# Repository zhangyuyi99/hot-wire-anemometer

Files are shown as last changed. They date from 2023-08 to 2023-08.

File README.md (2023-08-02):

# Hot wire anemometer

This project includes the design and implementation of a Wi-Fi enabled anemometer. The anemometer consists of a hardware portion which includes the PCB designs for the main board and logic board and a software portion which includes the firmware for operating the anemometer. The anemometer uses a hot wire method for wind speed measurement, and it includes a function to monitor battery voltage, disabling wind readings when the voltage drops below 7V until it recovers.

## Contents
1. [Hardware](#Hardware)
2. [Software](#Software)
3. [Usage](#Usage)
4. [File Structure](#File-Structure)

## Hardware
The hardware part consists of two boards: 

### Main Board
The main board uses the analog hot wire anemometer method for wind measurement. It is powered and sends signal to the logic board.

### Logic Board
The logic board contains an ESP32 processor which receives signals from the main board. It sends the data either via a serial port or Wi-Fi. It also monitors the battery voltage and provides visual feedback using LEDs.

## Software
The software part consists of firmware written for the ESP32 processor. The firmware contains routines to read data from the main board, manage Wi-Fi connectivity, monitor battery voltage, and control LED indicators.

### Python Scripts
There are two Python scripts provided for reading data:

1. `read_from_esp32.py`: Reads data over Wi-Fi. To use this, the anemometer and the computer receiving data must be on the same Wi-Fi network.

2. `read_from_esp32_serial.py`: Reads data over a serial port.

## Usage

To use this anemometer, you will need to:

1. Print the main board and logic board based on the provided PCB design files.
2. Perform necessary wirings to power up the main board and send signals to the logic board.
3. Set up Wi-Fi connectivity in the firmware.
4. Compile and upload the firmware to the logic board.
5. Calibrate the anemometer. To calibrate, place the anemometer in an environment with the same ambient temperature as the actual measurement environment. Adjust the Through Hole Potentiometer on each anemometer until the no-wind reading reaches 1000-1200. Each anemometer is paired with a green LED on the logic board. The LED lights up when the no-wind reading is in the desired range.
6. Run the provided Python scripts to receive and save the wind data. Each wind data packet is a string of numbers separated by commas. The first number is a timestamp, and the rest are the anemometer readings.

## Modes

The anemometer supports four running modes:
* READ_ANEMOMETER
* SEND_PIN_READ
* PRINT_IP
* CALIBRATE

The default mode is CALIBRATE.

## File Structure

The files in this project are organized as follows:

- plot.pptx
- logic_board/
    - Various KiCAD and SVG files for logic board design
- main_board/
    - Various KiCAD and SVG files for main board design
- firmware/
    - anemometer/
        - Python scripts to read data from the anemometer
        - ESP32 firmware files
        - Additional files for Visual Studio Code and PlatformIO

For a detailed view of the file structure, refer to the file list provided earlier.

## Note

The readings of different anemometers for the same wind strength might not be the same. However, the change in readings should accurately reflect the changes in wind conditions.

## Contribution 

The design of main board and logic board is done by Filip Ayazi. The firmware is written by Yuyi Zhang and ChatGPT, actually mostly by ChatGPT.

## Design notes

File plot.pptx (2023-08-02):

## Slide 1

9

8

Connection2
ADC 1
GPIO 2

Connection9
ADC 0
GPIO 1

Connection5
ADC 9
GPIO 10

Connection
ADC 8
GPIO 9

Anemometer | GPIO
1 | 4
2 | 2
3 | 10
4 | 3
5 | 8
6 | 5
7 | 9
8 | 1
9 | 7

7

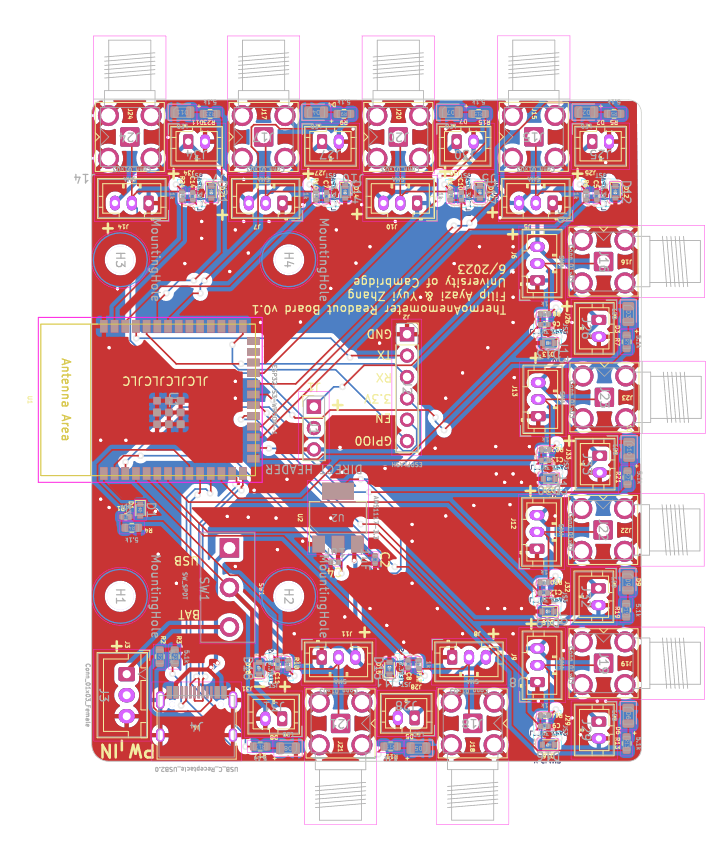
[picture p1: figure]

6

Connection 1
ADC 2
GPIO 3

5

Connection 8
ADC 7
GPIO 8

4

Connection 7
ADC 6
GPIO 7

3

2

Connection 6
ADC3
GPIO4

Connection 3
ADC4
GPIO5

1

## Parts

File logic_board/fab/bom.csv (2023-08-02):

Comment | Designator | Footprint | LCSC
DIRECT_HEADER | J1 | Connector_PinHeader_2.54mm:PinHeader_1x03_P2.54mm_Vertical | C5116482
USB_C_Receptacle_USB2.0 | J4 | Connector_USB:USB_C_Receptacle_HRO_TYPE-C-31-M-12 | C2765186
3.3V | D1,D12,D13,D14,D15,D16,D17,D18,D19,D20,D21 | Diode_SMD:D_SOD-523 | C2999960
1uF | C2,C4,C5,C6,C7,C8,C9,C10,C11,C12,C13,C14 | Capacitor_SMD:C_0402_1005Metric | C301999
10k | R1 | Resistor_SMD:R_0402_1005Metric | C407753
Conn_01x03_Female | J3 | Connector_JST:JST_XH_B3B-XH-A_1x03_P2.50mm_Vertical | C144394
5.1k | R2,R3,R4,R5,R7,R9,R11,R13,R15,R17,R19,R21,R23 | Resistor_SMD:R_0603_1608Metric | C25197
SW_SPDT | SW1 | library:switch_4.7mm | C319012
ESP32-S3-WROOM-1 | U1 | PCM_Espressif:ESP32-S3-WROOM-1 | C2913197
AMS1117-3.3 | U2 | Package_TO_SOT_SMD:SOT-223-3_TabPin2 | C173386
ESPFLASH | J2 | Connector_PinSocket_2.54mm:PinSocket_1x06_P2.54mm_Vertical | C5224026
JST | J25,J26,J27,J28,J29,J30,J31,J32,J33,J34 | Connector_JST:JST_PH_B2B-PH-K_1x02_P2.00mm_Vertical | C131337
SMA | J15,J16,J17,J18,J19,J20,J21,J22,J23,J24 | library:SMA_Amphenol_901-143_Horizontal | C411575
1k | R6,R8,R10,R12,R14,R16,R18,R20,R22,R24 | Resistor_SMD:R_0402_1005Metric | C208774
LED | D2,D3,D4,D5,D6,D7,D8,D9,D10,D11 | LED_SMD:LED_0805_2012Metric | C2297
Conn_01x03 | J5,J6,J7,J8,J9,J10,J11,J12,J13,J14 | Connector_JST:JST_PH_B3B-PH-K_1x03_P2.00mm_Vertical | C131339

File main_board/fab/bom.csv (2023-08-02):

Comment | Designator | Footprint | LCSC
HEADER | J3 | Connector_PinSocket_2.54mm:PinSocket_1x03_P2.54mm_Vertical | C358717
1nF | C5 | Capacitor_SMD:C_0402_1005Metric | C93920
PWR | J6 | Connector_JST:JST_PH_B2B-PH-K_1x02_P2.00mm_Vertical | C131337
470nF | C1,C4 | Capacitor_SMD:C_0402_1005Metric | C426055
AZ1117-5.0 | U3 | Package_TO_SOT_SMD:SOT-89-3 | C24248
wire+ | J1 | Library:m2.5_pad
wire- | J2 | Library:m2.5_pad
10k | R5 | Resistor_SMD:R_0603_1608Metric | C160601
47k | R3,R4 | Resistor_SMD:R_0603_1608Metric | C340515
JST3 | J7 | Connector_JST:JST_PH_B3B-PH-K_1x03_P2.00mm_Vertical | C131339
1K | R2 | Resistor_SMD:R_0603_1608Metric | C103198
SMA | J5 | Connector_Coaxial:SMA_Amphenol_901-143_Horizontal | C411575
5.1 | R1 | Resistor_SMD:R_2512_6332Metric | C105134
1uF | C2,C3 | Capacitor_SMD:C_0603_1608Metric | C106848
12k | R6 | Resistor_SMD:R_0603_1608Metric | C2984432
LM317_TO-220 | U2 | Package_TO_SOT_SMD:SOT-223 | C347367
10k | RV1 | Potentiometer_THT:Potentiometer_Bourns_3386P_Vertical | C118953
LM358 | U1 | Package_SO:SOP-8_3.76x4.96mm_P1.27mm | C5252902

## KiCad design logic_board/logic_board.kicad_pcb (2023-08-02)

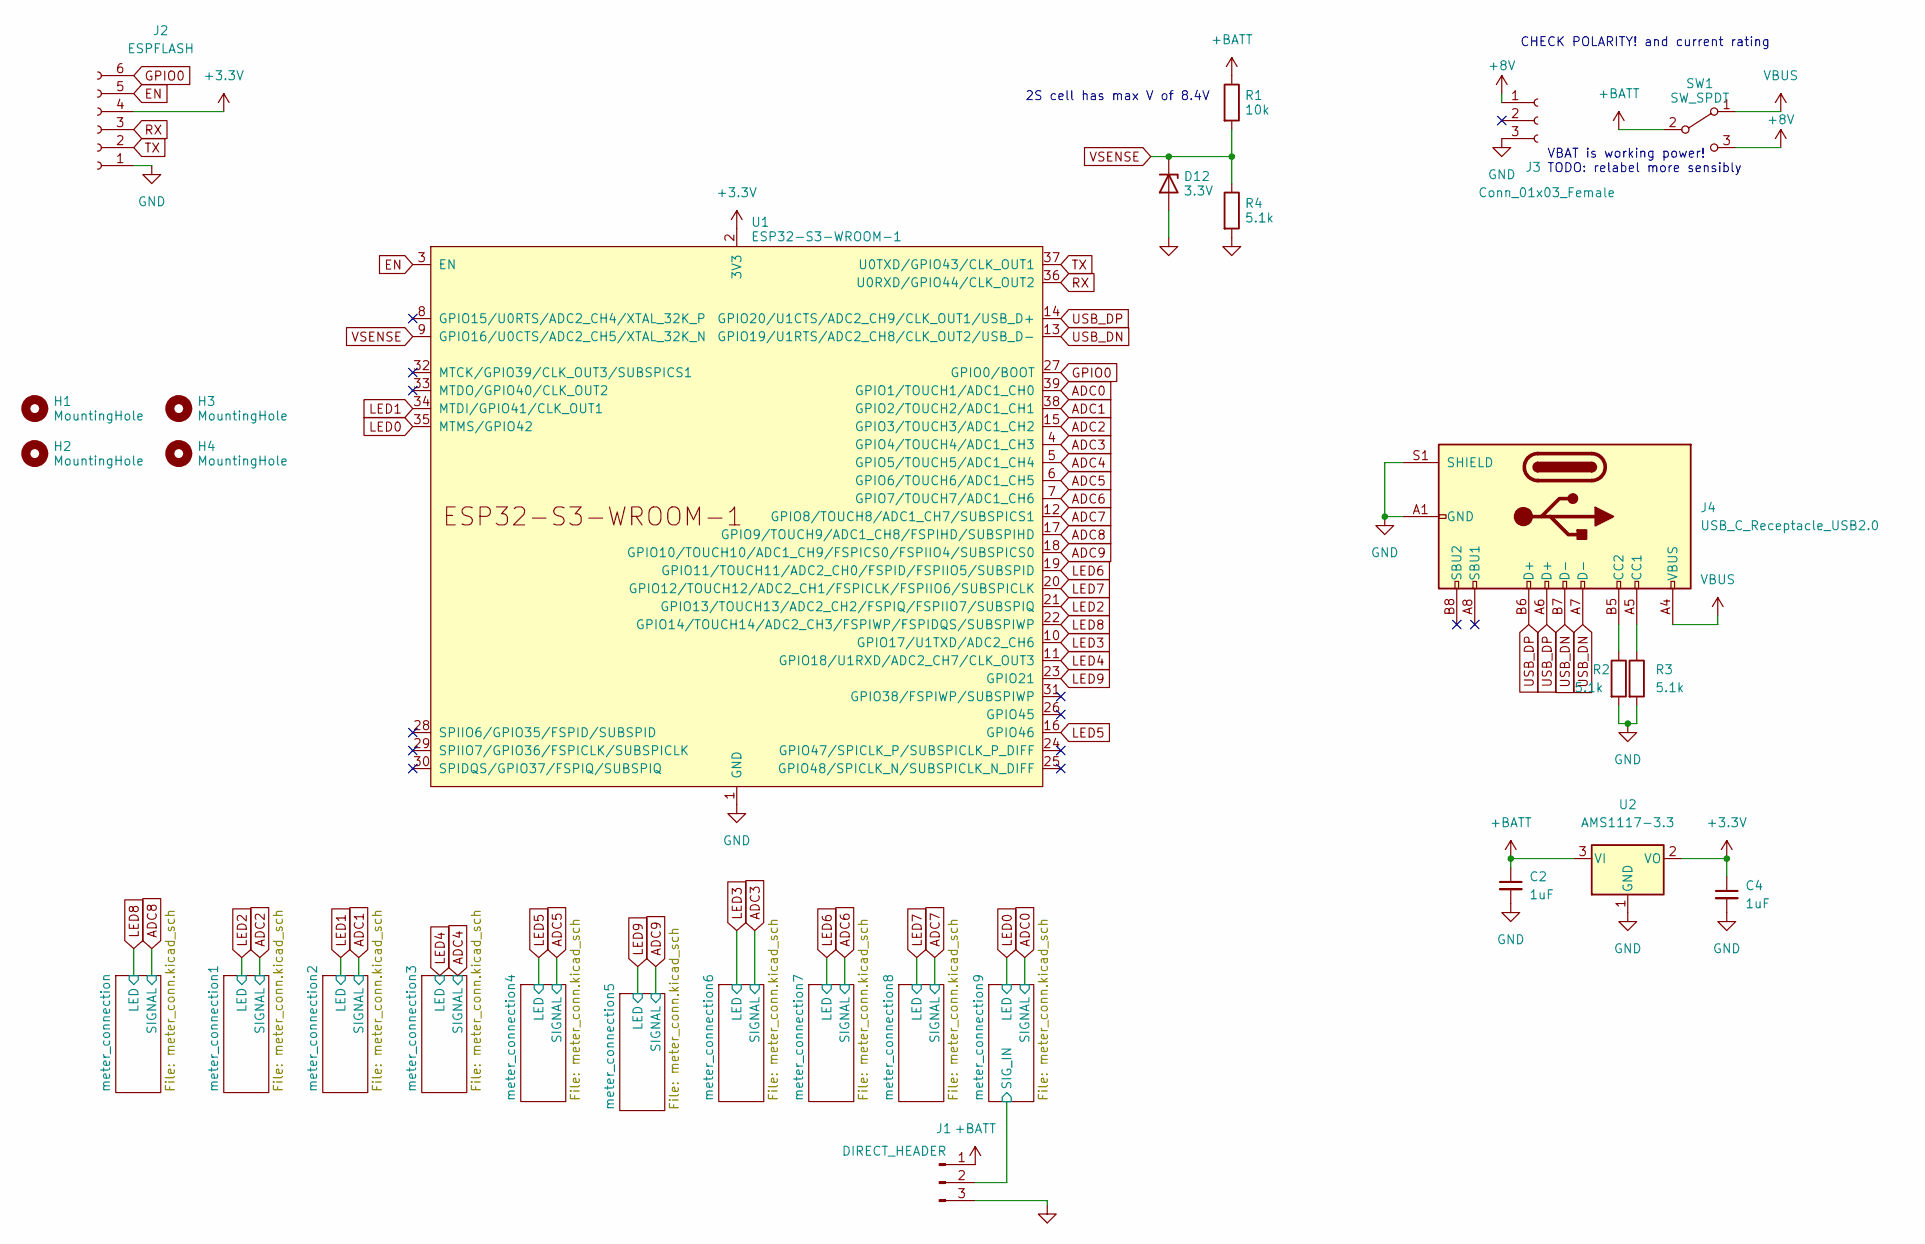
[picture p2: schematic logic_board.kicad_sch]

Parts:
C2, C4: 1uF; C_0402_1005Metric; JLC C83063
D12: 3.3V; D_SOD-523; JLC C2999960
H1, H2, H3, H4: MountingHole; MountingHole_3.2mm_M3
J1: DIRECT_HEADER; PinHeader_1x03_P2.54mm_Vertical; JLC C5116482
J2: ESPFLASH; PinSocket_1x06_P2.54mm_Vertical; JLC C5224026
J3: Conn_01x03_Female; JST_XH_B3B-XH-A_1x03_P2.50mm_Vertical; JLC C144394
J4: USB_C_Receptacle_USB2.0; USB_C_Receptacle_HRO_TYPE-C-31-M-12; JLC C2765186
R1: 10k; R_0402_1005Metric; JLC C407753
R2, R3, R4: 5.1k; R_0603_1608Metric; JLC C105580
SW1: SW_SPDT; switch_4.7mm; JLC C319012
U1: ESP32-S3-WROOM-1; JLC C2913197
U2: AMS1117-3.3; SOT-223-3_TabPin2; JLC C173386

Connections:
+3V3: C4.1, J2.4, U1.2 (3V3), U2.2 (VO)
+8V: J3.1, SW1.3 (C)
+BATT: C2.1, J1.1, R1.1, SW1.2 (B), U2.3 (VI); also elsewhere on the board
/meter_connection9/SIG_IN: J1.2; also elsewhere on the board
ADC0: U1.39 (GPIO1/TOUCH1/ADC1_CH0); also elsewhere on the board
ADC1: U1.38 (GPIO2/TOUCH2/ADC1_CH1); also elsewhere on the board
ADC2: U1.15 (GPIO3/TOUCH3/ADC1_CH2); also elsewhere on the board
ADC3: U1.4 (GPIO4/TOUCH4/ADC1_CH3); also elsewhere on the board
ADC4: U1.5 (GPIO5/TOUCH5/ADC1_CH4); also elsewhere on the board
ADC5: U1.6 (GPIO6/TOUCH6/ADC1_CH5); also elsewhere on the board
ADC6: U1.7 (GPIO7/TOUCH7/ADC1_CH6); also elsewhere on the board
ADC7: U1.12 (GPIO8/TOUCH8/ADC1_CH7/SUBSPICS1); also elsewhere on the board
ADC8: U1.17 (GPIO9/TOUCH9/ADC1_CH8/FSPIHD/SUBSPIHD); also elsewhere on the board
ADC9: U1.18 (GPIO10/TOUCH10/ADC1_CH9/FSPICS0/FSPIIO4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); also elsewhere on the board
EN: J2.5, U1.3 (EN)
GND: C2.2, C4.2, D12.2 (A), J1.3, J2.1, J3.3, J4.A1 (GND), J4.A12 (GND), J4.B1 (GND), J4.B12 (GND), J4.S1 (SHIELD), R2.2, R3.2, R4.2, U1.1 (GND), U1.40 (GND), U1.41 (GND), U2.1 (GND); also elsewhere on the board
GPIO0: J2.6, U1.27 (GPIO0/BOOT)
LED0: U1.35 (MTMS/GPIO42); also elsewhere on the board
LED1: U1.34 (MTDI/GPIO41/CLK_OUT1); also elsewhere on the board
LED2: U1.21 (GPIO13/TOUCH13/ADC2_CH2/FSPIQ/FSPIIO7/S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); also elsewhere on the board
LED3: U1.10 (GPIO17/U1TXD/ADC2_CH6); also elsewhere on the board
LED4: U1.11 (GPIO18/U1RXD/ADC2_CH7/CLK_OUT3); also elsewhere on the board
LED5: U1.16 (GPIO46); also elsewhere on the board
LED6: U1.19 (GPIO11/TOUCH11/ADC2_CH0/FSPID/FSPIIO5/S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); also elsewhere on the board
LED7: U1.20 (GPIO12/TOUCH12/ADC2_CH1/FSPICLK/FSPIIO6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); also elsewhere on the board
LED8: U1.22 (GPIO14/TOUCH14/ADC2_CH3/FSPIWP/FSPIDQS/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); also elsewhere on the board
LED9: U1.23 (GPIO21); also elsewhere on the board
unnamed: J4.A5 (CC1), R3.1
unnamed: J4.B5 (CC2), R2.1
RX: J2.3, U1.36 (U0RXD/GPIO44/CLK_OUT2)
TX: J2.2, U1.37 (U0TXD/GPIO43/CLK_OUT1)
USB_DN: J4.A7 (D-), J4.B7 (D-), U1.13 (GPIO19/U1RTS/ADC2_CH8/CLK_OUT2/USB_D-)
USB_DP: J4.A6 (D+), J4.B6 (D+), U1.14 (GPIO20/U1CTS/ADC2_CH9/CLK_OUT1/USB_D+)
VBUS: J4.A4 (VBUS), J4.A9 (VBUS), J4.B4 (VBUS), J4.B9 (VBUS), SW1.1 (A)

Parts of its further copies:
D1, D13, D14, D15, D16, D17, D18, D19, D20, D21: 3.3V; D_SOD-523; JLC C2999960

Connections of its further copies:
GND: D1.2 (A), D13.2 (A), D14.2 (A), D15.2 (A), D16.2 (A), D17.2 (A), D18.2 (A), D19.2 (A), D20.2 (A), D21.2 (A); also elsewhere on the board
unnamed 46: D13.1 (K); also elsewhere on the board
unnamed 47: D14.1 (K); also elsewhere on the board
unnamed 48: D15.1 (K); also elsewhere on the board
unnamed 49: D16.1 (K); also elsewhere on the board
unnamed 50: D17.1 (K); also elsewhere on the board
unnamed 51: D18.1 (K); also elsewhere on the board
unnamed 52: D19.1 (K); also elsewhere on the board
unnamed 53: D20.1 (K); also elsewhere on the board
unnamed 54: D21.1 (K); also elsewhere on the board

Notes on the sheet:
2S cell has max V of 8.4V
VBAT is working power! TODO: relabel more sensibly
CHECK POLARITY! and current rating

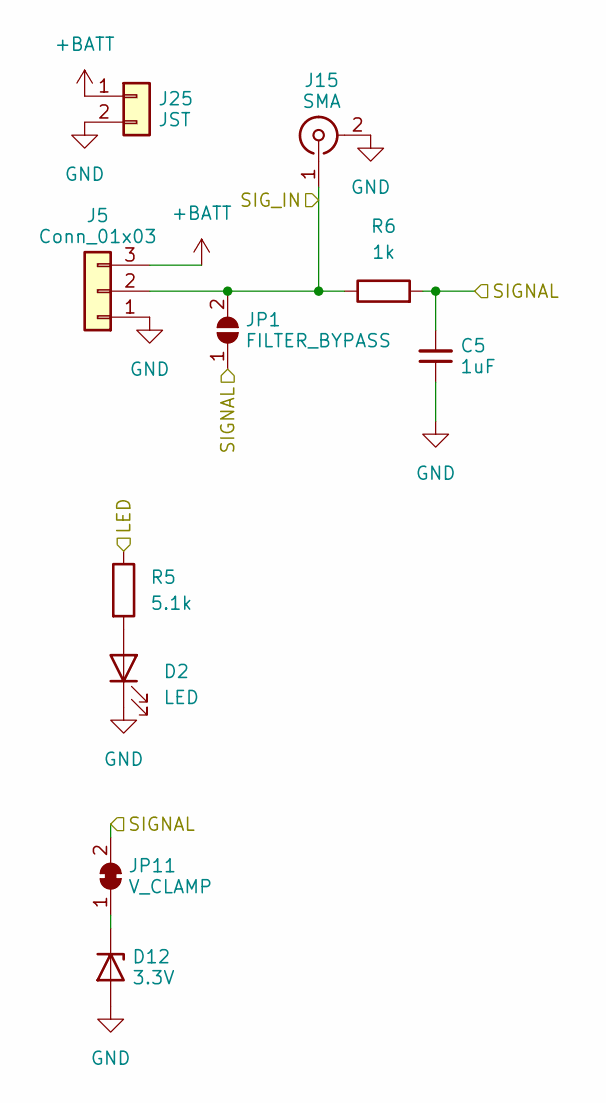
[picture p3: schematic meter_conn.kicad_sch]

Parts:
C5: 1uF; C_0402_1005Metric; JLC C83063
D2: LED; LED_0805_2012Metric; JLC C2297
D12: 3.3V; D_SOD-523; JLC C2999960
J5: Conn_01x03; JST_PH_B3B-PH-K_1x03_P2.00mm_Vertical; JLC C131339
J15: SMA; SMA_Amphenol_901-143_Horizontal; JLC C411575
J25: JST; JST_PH_B2B-PH-K_1x02_P2.00mm_Vertical; JLC C131337
JP1: FILTER_BYPASS; SolderJumper-2_P1.3mm_Open_RoundedPad1.0x1.5mm
JP11: V_CLAMP; SolderJumper-2_P1.3mm_Bridged2Bar_RoundedPad1.0x1.5mm
R5: 5.1k; R_0603_1608Metric; JLC C105580
R6: 1k; R_0402_1005Metric; JLC C208774

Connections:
+BATT: J5.3, J25.1; also elsewhere on the board
/meter_connection/SIG_IN: J5.2, J15.1 (In), JP1.2 (B), R6.1
ADC8: C5.2, JP1.1 (A), JP11.2 (B), R6.2; also elsewhere on the board
GND: C5.1, D2.1 (K), D12.2 (A), J5.1, J15.2 (Ext), J25.2; also elsewhere on the board
LED8: R5.1; also elsewhere on the board
unnamed: D2.2 (A), R5.2

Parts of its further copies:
C6, C7, C8, C9, C10, C11, C12, C13, C14: 1uF; C_0402_1005Metric; JLC C83063
D3, D4, D5, D6, D7, D8, D9, D10, D11: LED; LED_0805_2012Metric; JLC C2297
D13, D14, D15, D16, D17, D18, D19, D20, D21: 3.3V; D_SOD-523; JLC C2999960
J6, J7, J8, J9, J10, J11, J12, J13, J14: Conn_01x03; JST_PH_B3B-PH-K_1x03_P2.00mm_Vertical; JLC C131339
J16, J17, J18, J19, J20, J21, J22, J23, J24: SMA; SMA_Amphenol_901-143_Horizontal; JLC C411575
J26, J27, J28, J29, J30, J31, J32, J33, J34: JST; JST_PH_B2B-PH-K_1x02_P2.00mm_Vertical; JLC C131337
JP2, JP3, JP4, JP5, JP6, JP7, JP8, JP9, JP10: FILTER_BYPASS; SolderJumper-2_P1.3mm_Open_RoundedPad1.0x1.5mm
JP12, JP13, JP14, JP15, JP16, JP17, JP18, JP19, JP20: V_CLAMP; SolderJumper-2_P1.3mm_Bridged2Bar_RoundedPad1.0x1.5mm
R7, R9, R11, R13, R15, R17, R19, R21, R23: 5.1k; R_0603_1608Metric; JLC C105580
R8, R10, R12, R14, R16, R18, R20, R22, R24: 1k; R_0402_1005Metric; JLC C208774

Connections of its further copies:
+BATT: J6.3, J7.3, J8.3, J9.3, J10.3, J11.3, J12.3, J13.3, J14.3, J26.1, J27.1, J28.1, J29.1, J30.1, J31.1, J32.1, J33.1, J34.1; also elsewhere on the board
/meter_connection1/SIG_IN: J6.2, J16.1 (In), JP2.2 (B), R8.1
/meter_connection2/SIG_IN: J7.2, J17.1 (In), JP3.2 (B), R10.1
/meter_connection3/SIG_IN: J8.2, J18.1 (In), JP4.2 (B), R12.1
/meter_connection4/SIG_IN: J9.2, J19.1 (In), JP5.2 (B), R14.1
/meter_connection5/SIG_IN: J10.2, J20.1 (In), JP6.2 (B), R16.1
/meter_connection6/SIG_IN: J11.2, J21.1 (In), JP7.2 (B), R18.1
/meter_connection7/SIG_IN: J12.2, J22.1 (In), JP8.2 (B), R20.1
/meter_connection8/SIG_IN: J13.2, J23.1 (In), JP9.2 (B), R22.1
/meter_connection9/SIG_IN: J14.2, J24.1 (In), JP10.2 (B), R24.1; also elsewhere on the board
ADC0: C14.2, JP10.1 (A), JP20.2 (B), R24.2; also elsewhere on the board
ADC1: C7.2, JP3.1 (A), JP13.2 (B), R10.2; also elsewhere on the board
ADC2: C6.2, JP2.1 (A), JP12.2 (B), R8.2; also elsewhere on the board
ADC3: C11.2, JP7.1 (A), JP17.2 (B), R18.2; also elsewhere on the board
ADC4: C8.2, JP4.1 (A), JP14.2 (B), R12.2; also elsewhere on the board
ADC5: C9.2, JP5.1 (A), JP15.2 (B), R14.2; also elsewhere on the board
ADC6: C12.2, JP8.1 (A), JP18.2 (B), R20.2; also elsewhere on the board
ADC7: C13.2, JP9.1 (A), JP19.2 (B), R22.2; also elsewhere on the board
ADC9: C10.2, JP6.1 (A), JP16.2 (B), R16.2; also elsewhere on the board
GND: C6.1, C7.1, C8.1, C9.1, C10.1, C11.1, C12.1, C13.1, C14.1, D3.1 (K), D4.1 (K), D5.1 (K), D6.1 (K), D7.1 (K), D8.1 (K), D9.1 (K), D10.1 (K), D11.1 (K), D13.2 (A), D14.2 (A), D15.2 (A), D16.2 (A), D17.2 (A), D18.2 (A), D19.2 (A), D20.2 (A), D21.2 (A), J6.1, J7.1, J8.1, J9.1, J10.1, J11.1, J12.1, J13.1, J14.1, J16.2 (Ext), J17.2 (Ext), J18.2 (Ext), J19.2 (Ext), J20.2 (Ext), J21.2 (Ext), J22.2 (Ext), J23.2 (Ext), J24.2 (Ext), J26.2, J27.2, J28.2, J29.2, J30.2, J31.2, J32.2, J33.2, J34.2; also elsewhere on the board
LED0: R23.1; also elsewhere on the board
LED1: R9.1; also elsewhere on the board
LED2: R7.1; also elsewhere on the board
LED3: R17.1; also elsewhere on the board
LED4: R11.1; also elsewhere on the board
LED5: R13.1; also elsewhere on the board
LED6: R19.1; also elsewhere on the board
LED7: R21.1; also elsewhere on the board
LED9: R15.1; also elsewhere on the board
unnamed: D3.2 (A), R7.2
unnamed: D4.2 (A), R9.2
unnamed: D5.2 (A), R11.2
unnamed: D6.2 (A), R13.2
unnamed: D7.2 (A), R15.2
unnamed: D8.2 (A), R17.2
unnamed: D9.2 (A), R19.2
unnamed: D10.2 (A), R21.2
unnamed: D11.2 (A), R23.2
unnamed: D13.1 (K), JP12.1 (A)
unnamed: D14.1 (K), JP13.1 (A)
unnamed: D15.1 (K), JP14.1 (A)
unnamed: D16.1 (K), JP15.1 (A)
unnamed: D17.1 (K), JP16.1 (A)
unnamed: D18.1 (K), JP17.1 (A)
unnamed: D19.1 (K), JP18.1 (A)
unnamed: D20.1 (K), JP19.1 (A)
unnamed: D21.1 (K), JP20.1 (A)

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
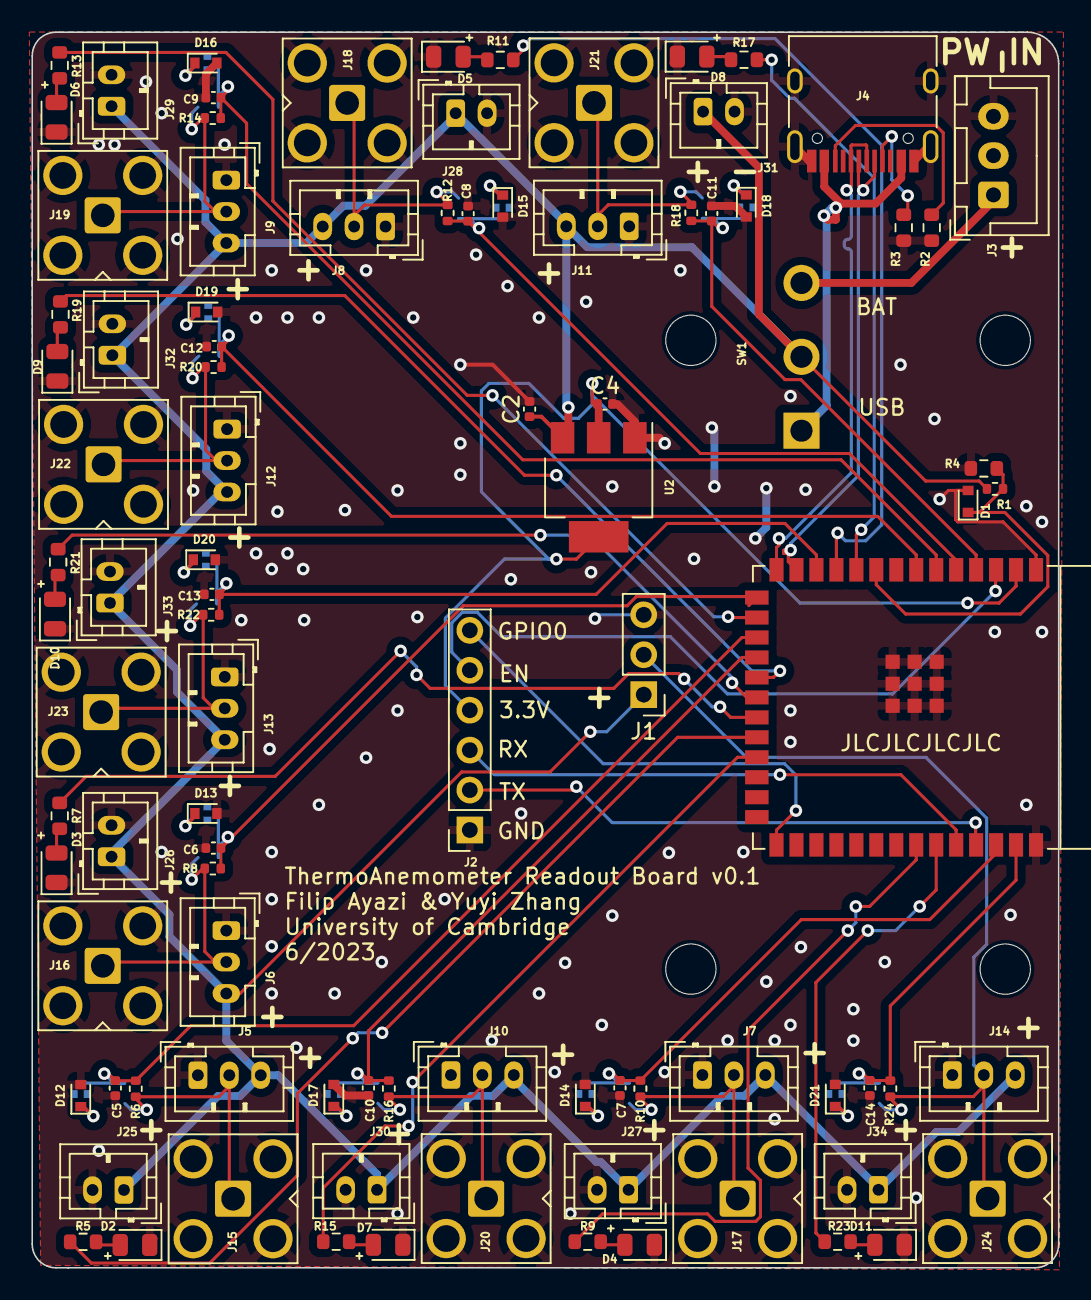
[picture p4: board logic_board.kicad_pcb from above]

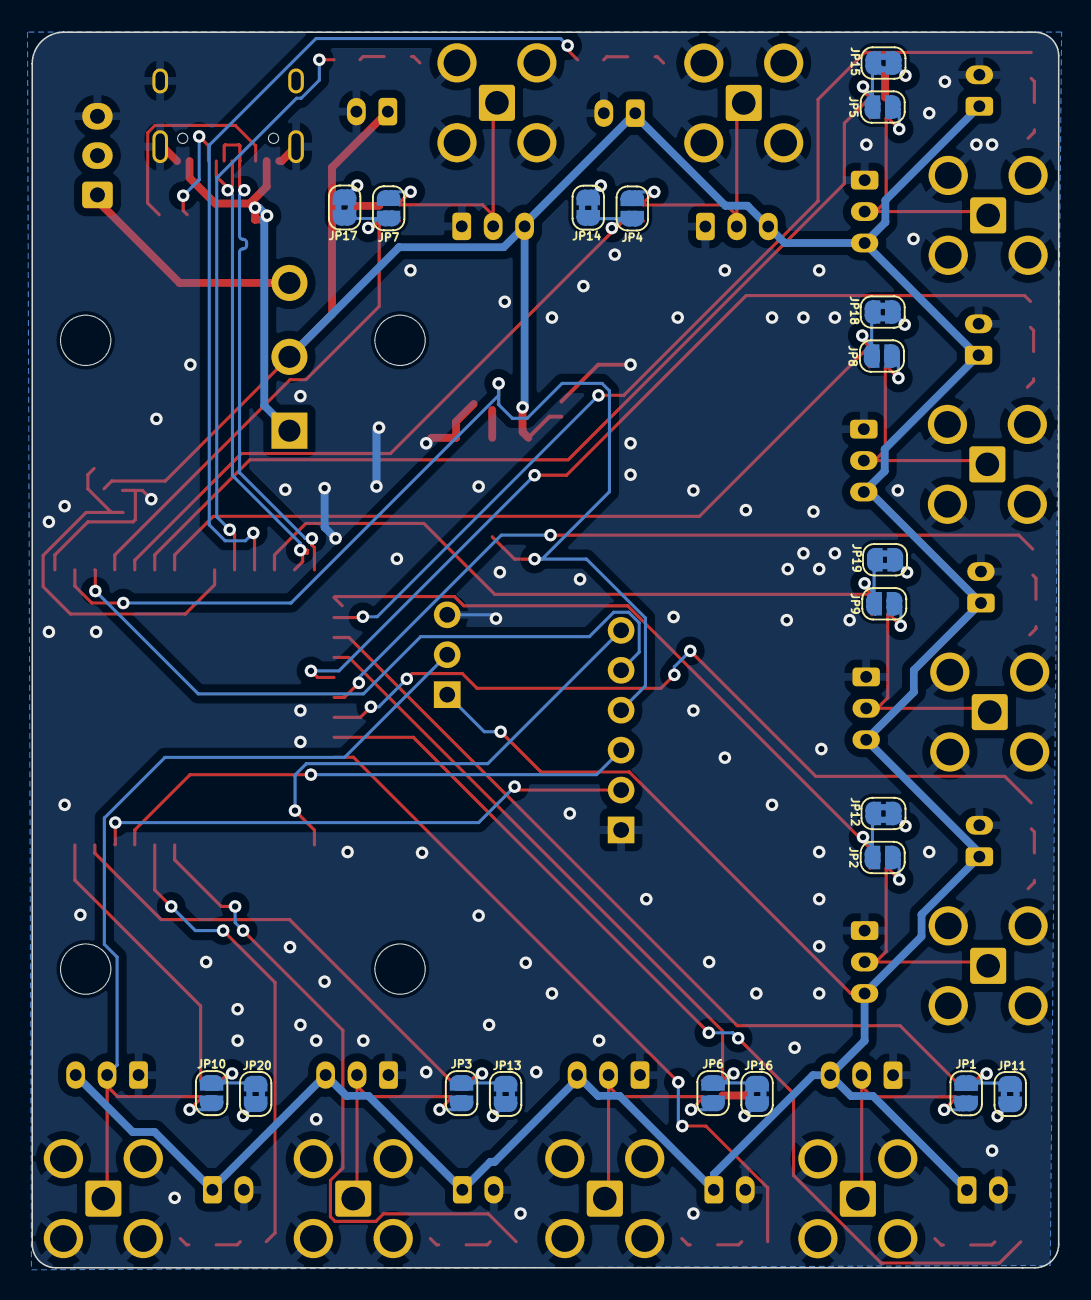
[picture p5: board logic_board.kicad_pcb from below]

Board: 2 copper layers, 65.3 x 78.6 mm, 118 parts (20 on the bottom side), 64 nets.

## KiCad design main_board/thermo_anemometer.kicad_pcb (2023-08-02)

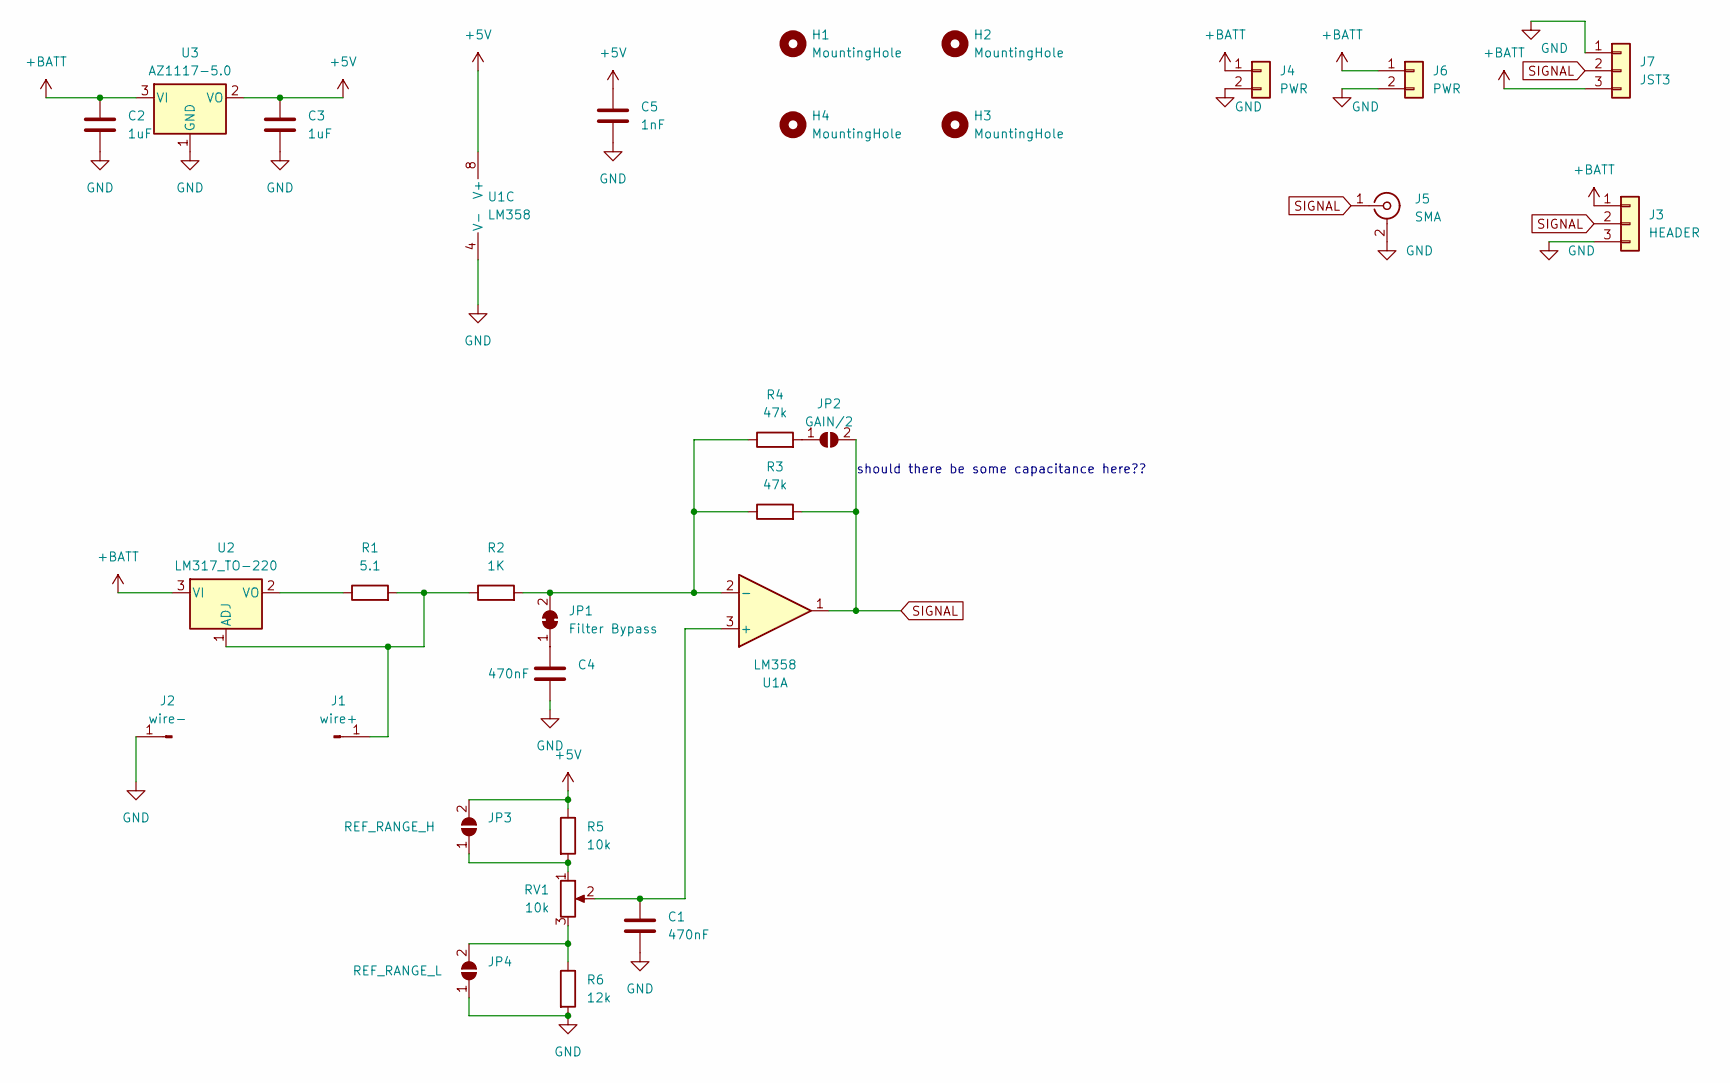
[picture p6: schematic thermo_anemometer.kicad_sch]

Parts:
C1, C4: 470nF; C_0402_1005Metric; JLC C426055
C2, C3: 1uF; C_0603_1608Metric; JLC C106848
C5: 1nF; C_0402_1005Metric; JLC C93920
H1, H2, H3, H4: MountingHole; MountingHole_3.2mm_M3
J1: wire+; m2.5_pad
J2: wire-; m2.5_pad
J3: HEADER; PinSocket_1x03_P2.54mm_Vertical; JLC C358717
J4: PWR; SolderWire-0.5sqmm_1x02_P4.6mm_D0.9mm_OD2.1mm
J5: SMA; SMA_Amphenol_901-143_Horizontal; JLC C411575
J6: PWR; JST_PH_B2B-PH-K_1x02_P2.00mm_Vertical; JLC C131337
J7: JST3; JST_PH_B3B-PH-K_1x03_P2.00mm_Vertical; JLC C131339
JP1: Filter Bypass; SolderJumper-2_P1.3mm_Bridged_RoundedPad1.0x1.5mm
JP2: GAIN/2; SolderJumper-2_P1.3mm_Open_RoundedPad1.0x1.5mm
JP3: REF_RANGE_H; SolderJumper-2_P1.3mm_Open_RoundedPad1.0x1.5mm
JP4: REF_RANGE_L; SolderJumper-2_P1.3mm_Open_RoundedPad1.0x1.5mm
R1: 5.1; R_2512_6332Metric; JLC C105134
R2: 1K; R_0603_1608Metric; JLC C103198
R3, R4: 47k; R_0603_1608Metric; JLC C340515
R5: 10k; R_0603_1608Metric; JLC C160601
R6: 12k; R_0603_1608Metric; JLC C2984432
RV1: 10k; Potentiometer_Bourns_3386P_Vertical; JLC C118953
U1: LM358; SOP-8_3.76x4.96mm_P1.27mm; JLC C5252902
U2: LM317_TO-220; SOT-223; JLC C347367
U3: AZ1117-5.0; SOT-89-3; JLC C24248

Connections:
+5V: C3.1, C5.1, JP3.2 (B), R5.1, U1.8 (V+), U3.2 (VO)
+BATT: C2.1, J3.1, J4.1, J6.1, J7.3, U2.3 (VI), U3.3 (VI)
GND: C1.2, C2.2, C3.2, C4.2, C5.2, J2.1, J3.3, J4.2, J5.2 (Ext), J6.2, J7.1, JP4.1 (A), R6.2, U1.4 (V-), U3.1 (GND)
unnamed: J1.1, R1.2, R2.1, U2.1 (ADJ)
unnamed: C4.1, JP1.1 (A)
unnamed: JP1.2 (B), R2.2, R3.1, R4.1, U1.2 (-)
unnamed: JP2.1 (A), R4.2
unnamed: JP3.1 (A), R5.2, RV1.1
unnamed: JP4.2 (B), R6.1, RV1.3
unnamed: C1.1, RV1.2, U1.3 (+)
unnamed: R1.1, U2.2 (VO)
SIGNAL: J3.2, J5.1 (In), J7.2, JP2.2 (B), R3.2, U1.1

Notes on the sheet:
should there be some capacitance here??

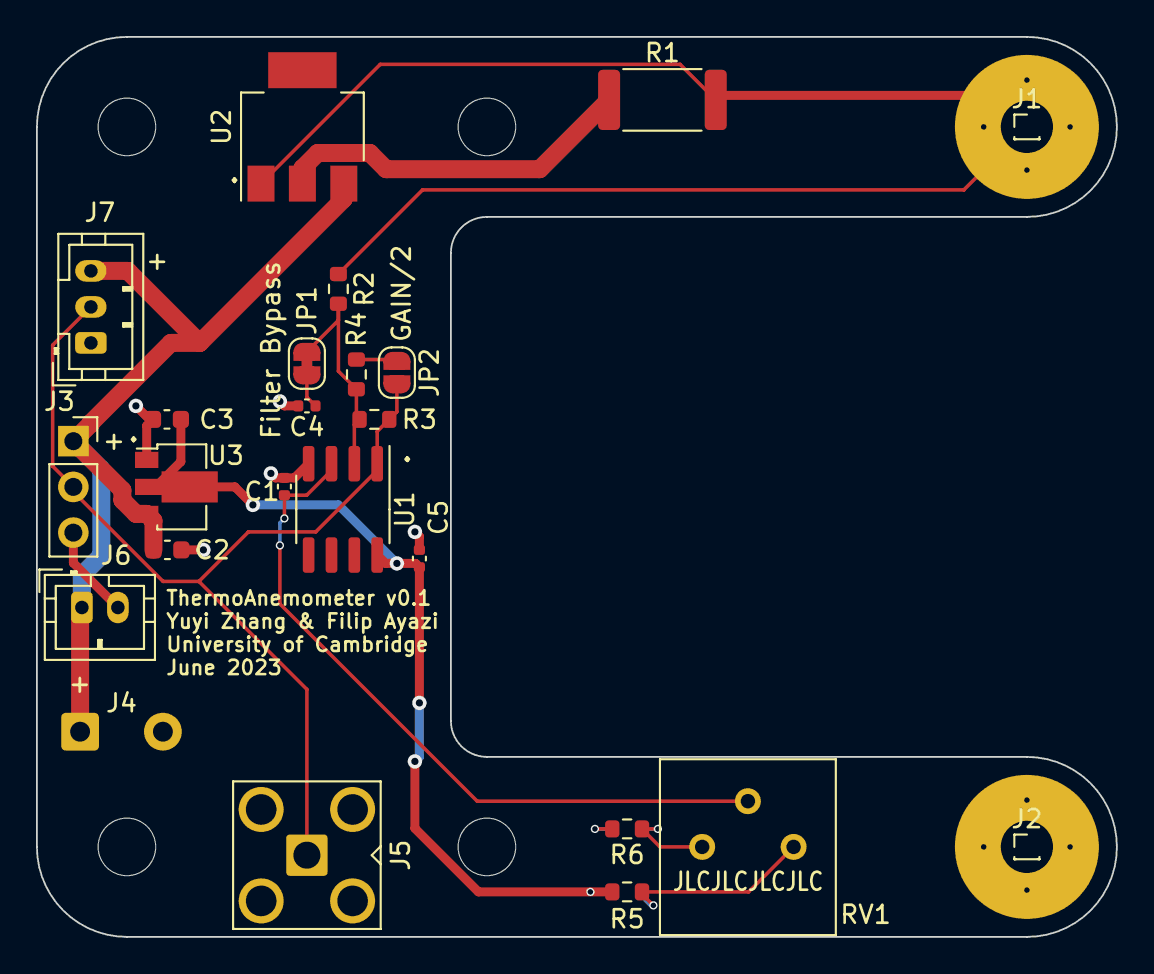
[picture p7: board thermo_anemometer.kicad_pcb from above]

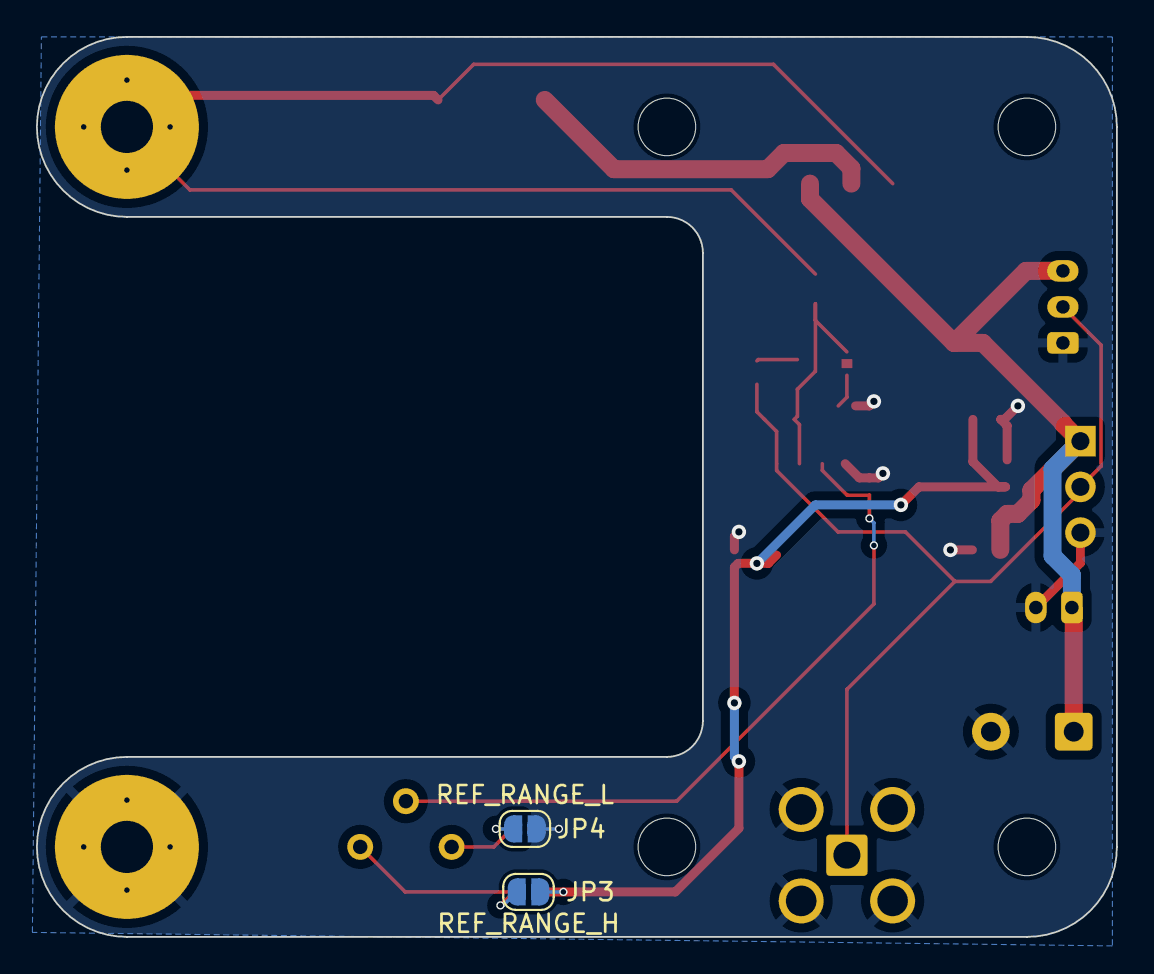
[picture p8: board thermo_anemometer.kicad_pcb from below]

Board: 2 copper layers, 60.0 x 50.0 mm, 30 parts (2 on the bottom side), 12 nets.

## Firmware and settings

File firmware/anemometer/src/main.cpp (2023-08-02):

#include <WiFi.h>
#include <WiFiClient.h>
#include <WebServer.h>

#define ANALOG_READ_PIN 32
#define LOW_BATTERY_VOLTAGE 7.0  // Low battery threshold
#define BATTERY_READ_PIN 16  // Replace with your battery read pin
#define R1 10000   // resistor values in battery circuit
#define R4 5100

const char* ssid = "Jimmy";
const char* password = "12345678";

WebServer server(80);

enum Mode {
  READ_ANEMOMETER,
  SEND_PIN_READ,
  PRINT_IP,
  CALIBRATE
};

Mode mode = CALIBRATE;

const int analog_pins[] = {1, 2, 3, 4, 5, 6, 7, 8, 9, 10};
const int led_pins[] = {42, 41, 13, 17, 18, 46, 11, 12, 14, 21};

void readAnemometer() {
  int result = analogRead(10);
  if (result > 950 && result < 1200)
    digitalWrite(21, HIGH);
  else
    digitalWrite(21, LOW);
  // Serial.println(result);
  delay(20);
}

void sendPinReadThroughWiFi() {
  server.handleClient();
}

void printIP() {
  if (WiFi.status() == WL_CONNECTED) {
    Serial.print("IP address: ");
    Serial.println(WiFi.localIP());
  }
}

void calibrate() {

  // Include the timestamp at the beginning of the response
  unsigned long timestamp = millis();
  Serial.print(String(timestamp));
  Serial.print(",");
  
  int pin_order[] = {4, 2, 10, 3, 8, 5, 9, 1, 7};  // specify the order here
  for (int i = 0; i < 9; i++) { // Change the loop to iterate over the length of the pin_order array
    int value = analogRead(pin_order[i]);
    Serial.print(String(value));
    if(i < 8) {
      Serial.print(",");
    }
    if (value >= 1000 && value <= 1200) {
      digitalWrite(led_pins[i], HIGH);
    } else {
      digitalWrite(led_pins[i], LOW);
    }
  }
  Serial.println();
  delay(10);  // wait for 10 milliseconds
}

void setup() {
  // Common setup
  Serial.begin(115200);

  // Setup for anemometer reading
  pinMode(21, OUTPUT);
  digitalWrite(21, HIGH);
  for (int i = 0; i < 1000000; i++);
  digitalWrite(21, LOW);
  delay(500);
  digitalWrite(21, HIGH);

  // configure BATTERY_READ_PIN as input
  pinMode(BATTERY_READ_PIN, INPUT); 

  // Setup for WiFi
  WiFi.begin(ssid, password);

  while (WiFi.status() != WL_CONNECTED) {
    delay(1000);
    Serial.println("Connecting to WiFi..");
  }

  Serial.println("Connected to WiFi");

  for (int i = 0; i < 10; i++) {
    pinMode(analog_pins[i], INPUT);
    pinMode(led_pins[i], OUTPUT);
  }

  server.on("/", HTTP_GET, []() {
    int pin_order[] = {4, 2, 10, 3, 8, 5, 9, 1, 7};  // specify the order here
    String response = "";

    // Include the timestamp at the beginning of the response
    unsigned long timestamp = millis();
    response += String(timestamp);
    response += ",";

    Serial.print(String(timestamp)); // print timestamp to Serial
    Serial.print(",");
    
    for (int i = 0; i < 9; i++) {
      int value = analogRead(pin_order[i]);
      response += String(value);
      if(i < 8) {
        response += ",";
      }
      
      // Print pin value to Serial
      Serial.print(String(value));
      if(i < 8) {
        Serial.print(",");
      }
      
      if (value >= 1000 && value <= 1200) {
        digitalWrite(led_pins[i], HIGH);
      } else {
        digitalWrite(led_pins[i], LOW);
      }
    }

    Serial.println(); // End the line on Serial
    
    server.send(200, "text/plain", response); // Send the response via WiFi
  });




  server.on("/mode/anemometer", HTTP_GET, []() {
    mode = READ_ANEMOMETER;
    server.send(200, "text/plain", "Switched to anemometer mode");
  });

  server.on("/mode/pinread", HTTP_GET, []() {
    mode = SEND_PIN_READ;
    server.send(200, "text/plain", "Switched to pin read mode");
  });

  server.on("/mode/ip", HTTP_GET, []() {
    mode = PRINT_IP;
    server.send(200, "text/plain", "Switched to IP print mode");
  });

  server.on("/mode/calibrate", HTTP_GET, []() {
    mode = CALIBRATE;
    server.send(200, "text/plain", "Switched to calibrate mode");
  });

  server.begin();
}

void loop() {
  // handle incoming client requests
  server.handleClient();

    // Read battery voltage
  float batteryVoltage = analogRead(BATTERY_READ_PIN) * (8.4 / 4095.0);  // adjust as necessary for your ADC

  float LOW_SIGNAL_VOLTAGE = LOW_BATTERY_VOLTAGE * R4 / (R1+R4);

  while (batteryVoltage <= LOW_SIGNAL_VOLTAGE) {
    for (int i = 0; i < 10; i++) {
      digitalWrite(led_pins[i], HIGH);  // turn ON the LEDs
    }
    delay(500);  // delay for half a second
    for (int i = 0; i < 10; i++) {
      digitalWrite(led_pins[i], LOW);  // turn OFF the LEDs
    }
    delay(500);  // delay for half a second

    batteryVoltage = analogRead(BATTERY_READ_PIN) * (8.4 / 4095.0);  // update the battery voltage value
  }

  switch (mode) {
    case READ_ANEMOMETER:
      readAnemometer();
      break;
    case SEND_PIN_READ:
      sendPinReadThroughWiFi();
      break;
    case PRINT_IP:
      printIP();
      break;
    case CALIBRATE:
      calibrate();
      break;
  }
}

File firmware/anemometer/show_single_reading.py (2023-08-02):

import serial
import matplotlib.pyplot as plt
import time
import matplotlib
matplotlib.use('TkAgg')


# the port might be different on your PC
ser = serial.Serial('COM3', 115200, timeout=1)

ser.flushInput()

plot_window = 100
y_var = [0]*plot_window
x_var = list(range(plot_window))
fig, ax = plt.subplots()
line, = ax.plot(x_var, y_var)

while True:
    try:
        ser_bytes = ser.readline()
        decoded_bytes = float(ser_bytes[0:len(ser_bytes) - 2].decode("utf-8"))
        print("Reading: ", decoded_bytes)  # print real time readings
        y_var.append(decoded_bytes)
        y_var = y_var[-plot_window:]
        line.set_ydata(y_var)
        ax.relim()
        ax.autoscale_view()
        fig.canvas.draw()
        plt.pause(0.01)  # add a short pause to allow GUI to update
        fig.canvas.flush_events()
    except:
        print("Keyboard Interrupt")
        break
